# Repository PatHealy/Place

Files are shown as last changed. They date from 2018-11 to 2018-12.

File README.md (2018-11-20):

# Place

VML/Place allows all users of the VML to leave their digital mark on the lab through playful interaction over the web!

[VML/Place](http://pathealy.pythonanywhere.com) has a mutable array of pixels that can be edited one at a time.

## Raspberry Pi
The brain of the displays is the Raspberry Pi.  It controls all of the arduino-controlled displays through addressed I2C communication.

The Pi contains this repository under `~/Desktop/VML-Place/Pi`.  To run the system, you'll need to either boot with the display or VNC/SSH into the Pi to start `PanelMaster.py`.

### Panel Master
The Panel Master uses a combination of `HTTP`, `SMBus`, and the custom `Panel` libraries to handle the web and I2C interaction.

Panels are entered into a 2D list which _should_ match the configuration on the website. The behavior is unexpected when there is a panel entered where there is no expected panel from the website.

## Arduino
Each panel is driven by an Arduino Uno or Arduino Mega with the [RGBMatrixPanel](https://github.com/adafruit/RGB-matrix-Panel) library from Adafruit.

Each Arduino must have a unique I2C address assigned to it on `line 22` of [MatrixPanel.ino](Arduino/MatrixPanel/MatrixPanel.ino).  Addresses must lie within the range of 0x04 and 0x7F and must be unique between panels. 

New panels can be made using the guide over at [Adafruit](https://learn.adafruit.com/32x16-32x32-rgb-led-matrix/overview).

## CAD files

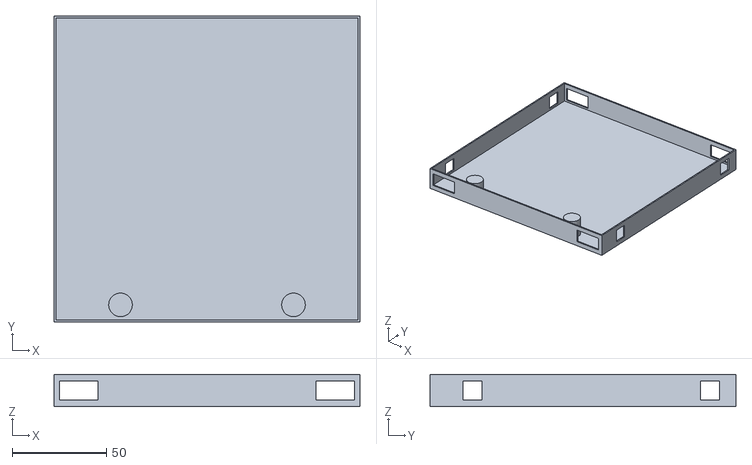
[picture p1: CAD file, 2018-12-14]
Housing/place.house.inner.stl
162.4 x 162.4 x 17.0

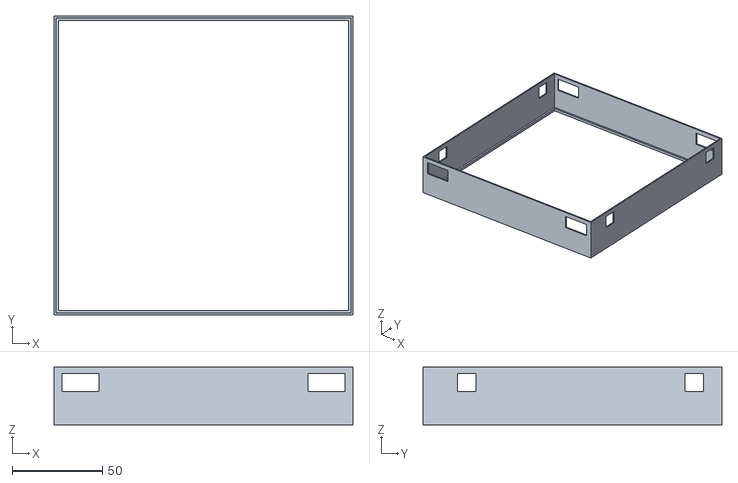
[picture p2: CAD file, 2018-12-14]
Housing/place.house.outer.stl
165.4 x 165.4 x 32.0

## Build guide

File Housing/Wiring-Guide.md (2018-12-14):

# VML/Place Panel Wiring Guide

## Materials

- [Adafruit 32x32 LED Panel](https://www.adafruit.com/product/1484)
- [Arduino Uno](https://store.arduino.cc/usa/arduino-uno-rev3)
- [Raspberry Pi](https://www.raspberrypi.org/products/raspberry-pi-3-model-b/)
- Jumper Wires

## Instructions

### Internal Wiring

Instructions for wiring the Adafruit panel inputs to the onboard Arduino Uno can be found [here](https://learn.adafruit.com/32x16-32x32-rgb-led-matrix/connecting-with-jumper-wires). Instructions for powering the panel can be found [here](https://learn.adafruit.com/32x16-32x32-rgb-led-matrix/powering).

As specified in these instructions, there are three ground ports on the panel. In order to reserve ground connections on the Arduino for later use, join these three connections and wire them to a single `GND` pin. Once the data connections have been made, split the power input to the panel and attach it with a jumper cable to the `5V` pin on the Arduino. Similarly, split the ground to the panel and attach to one of the two remaining `GND` pins on the Arduino.

### External Wiring

At this point, all necessary connections between the onboard Arduino and the LED panel have been made, so to check them power the devices and follow the directions [here](https://learn.adafruit.com/32x16-32x32-rgb-led-matrix/test-example-code) to perform some tests.

The only remaining step to take before casing the panel and Arduino is to set the wires for communication with the master controller. In this project, that is a Raspberry Pi and we will be using I2C communications protocols. To complete onboard wiring, attach jumpers to the `SDA`, `SCL`, and final remaining `GND` pins on the Arduino. These wires should be long enough to reach outside the panel if necessary, in order to form a common set of connections with all active panels and the master controller.

### Housing the Setup

Housing designs for the display and its onboard Arduino can be found [here](https://github.com/Vibrant-Media-Lab/Place/tree/master/Housing). The files are in a .stl format, and printing took us approximately 5.5 hours. We suggest using PLA as a material, but other print plastics will work as well. Once the components are completed. remove the support from the openings in them, and line up the inner and outer sections by those openings. You may need to tamp down wires to the back of the panel, but it should fit cleanly above the inner housing. Slide the outer housing down over the entire setup, ensuring the common `SDA`, `SCL`, and `GND` connections reach outside it. Using electrical tape or hot glue, connect the two pieces of housing at the back, and the project is complete!

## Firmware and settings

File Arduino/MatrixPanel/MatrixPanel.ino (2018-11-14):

#include <RGBmatrixPanel.h>
#include <Wire.h>

//#define CLK  8   // USE THIS ON ARDUINO UNO, ADAFRUIT METRO M0, etc.
//#define CLK A4 // USE THIS ON METRO M4 (not M0)
#define CLK 11 // USE THIS ON ARDUINO MEGA
#define OE   9
#define LAT 10
#define A   A0
#define B   A1
#define C   A2
#define D   A3

RGBmatrixPanel matrix(A, B, C, D, CLK, LAT, OE, false);

// int[c][x][y]
// c - color plane (r, g, b)
// x - x coordinate
// y - y coordinate
char matrix_data[3][32][32];

#define ADDR 0x04

void clearMatrix();
void setPixel(byte x, byte y, byte r, byte g, byte b);

void setup() {

  Wire.begin(ADDR);
  Wire.onReceive(receiveEvent);

  matrix.begin();

  // do some bootup display
  matrix.fillRect(0, 0, 32, 32, matrix.Color333(0, 0, 0));
  delay(1000);
  matrix.fillRect(0, 0, 32, 32, matrix.Color333(1, 0, 0));
  delay(1000);
  matrix.fillRect(0, 0, 32, 32, matrix.Color333(0, 1, 0));
  delay(1000);
  matrix.fillRect(0, 0, 32, 32, matrix.Color333(0, 0, 1));
  delay(1000);
  clearMatrix();
  delay(1000);
}

void loop() {
  
}

void clearMatrix(){
  for(int c = 0; c < 3; c++){
    for(int x = 0; x < 32; x++){
      for(int y = 0; y < 32; y++){
        setPixel((char)x, (char)y, (char)0, (char)0, (char)0);
      }
    }
  }
}

void setPixel(char x, char y, char r, char g, char b){
  matrix.drawPixel(x, y, matrix.Color888(matrix_data[0][x][y] = r, matrix_data[1][x][y] = g, matrix_data[2][x][y] = b));
  //matrix.drawPixel(x, y, matrix.Color333(r, g, b));
}

// byte 0 - set pixel (AF)
void receiveEvent(int howMany){
  Wire.read();
  if(!Wire.available()){
    return;
  }
  char type = Wire.read();

  if((byte)type == (byte)0xaf){ // draw pixel
    // byte 1 - x coordinate
    // byte 2 - y coordinate
    // byte 3 - r color
    // byte 4 - g color
    // byte 5 - b color
    char data[5];
    int i=0;
    
    while(Wire.available()){
      data[i] = (char)Wire.read();
      i++;
    }
    
    matrix.drawPixel(data[0], data[1], matrix.Color444(data[2], data[3], data[4]));
  } else if((byte)type == (byte)0xad){ // fill rect
    // byte 1 - x start coordinate
    // byte 2 - y start coordinate
    // byte 3 - x end coordinate
    // byte 4 - y end coordinate
    // byte 5 - r color
    // byte 6 - g color
    // byte 7 - b color
    char data[7];
    int i=0;
    
    while(Wire.available()){
      data[i] = (char)Wire.read();
      i++;
    }
    
    matrix.fillRect(data[0], data[1], data[2], data[3], matrix.Color444(data[4], data[5], data[6]));
  }

  while(Wire.available()){
    Wire.read();
  }
}

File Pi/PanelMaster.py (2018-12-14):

import smbus
import time

import urllib.request

from ServerConnector import Connector
from Panel import Panel

bus = smbus.SMBus(1)
ADDR = 0x04


WHITE_PIXEL = [0x1, 0x1, 0x1]
BLACK_PIXEL = [0x0, 0x0, 0x0]


panel1 = Panel(bus, 0x04)
#panel2 = Panel(bus, 0x05)

panels = [[panel1]]

color_grid = [[0 for x in range(15)] for y in range(15)]
color_grid[0][0] = [[[0 for x in range(3)] for y in range(32)] for z in range(32)]
color_grid[0][1] = [[[0 for x in range(3)] for y in range(32)] for z in range(32)]

#panel.fill_rect([0,0], [32,32], WHITE_PIXEL)

connector = Connector("http://pathealy.pythonanywhere.com/get_grid")
ticks = 0
ticked = False
wait_flag = False

while True:
    data = connector.get_dump()
    ticked = False
    for x in range(len(panels)):
        for y in range(len(panels[x])):
            try:
                if ticks % 5 == 0:
                    panels[0][0].draw_pixel([0,0], data[0][0][0][0])
                if(panels[x][y] is not None):
                    grid = data[x][y]
                    for i in range(len(grid)):
                        for j in range(len(grid[i])):
                            if not list(color_grid[x][y][j][i]) == list(grid[j][i]):
                                panels[x][y].draw_pixel([j, i], grid[j][i])
                                if waitFlag:
                                    time.sleep(6)
                                    panels[x][y].draw_pixel([j,i], grid[j][i])
                                    waitFlag = False
                                color_grid[x][y][j][i] = list(grid[j][i])
                                time.sleep(0.0001)
                                ticked = True
                                ticks = 0
                                
            except:
                print(y, " Failed")
                waitFlag = True
                color_grid[0][0] = [[[0 for x in range(3)] for y in range(32)] for z in range(32)]
                color_grid[0][1] = [[[0 for x in range(3)] for y in range(32)] for z in range(32)]
                time.sleep(6)                
    if not ticked:
        print("No update")
        ticks = ticks + 1
    if ticks > 100:
        time.sleep(60)
    elif ticks > 10:
        time.sleep(5)
    else:
        time.sleep(1)
    

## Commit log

2018-11-15 Updated Readme with RPi and Arduino panel information
2018-12-11 Fixed infinite web polling potential issue
    [PanelMaster.py]
2018-12-13 Create Wiring-Guide
